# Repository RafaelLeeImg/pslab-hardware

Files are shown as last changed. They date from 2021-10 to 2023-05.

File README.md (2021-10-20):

# PSLab Hardware





This is a special branch `diff-img` where the changes made on all four layers relative to the immediate previous board is presented as a diff image.

## Current Layers

<details>
  <summary>External Layers</summary>

| Top | Bottom |
| --- | --- |
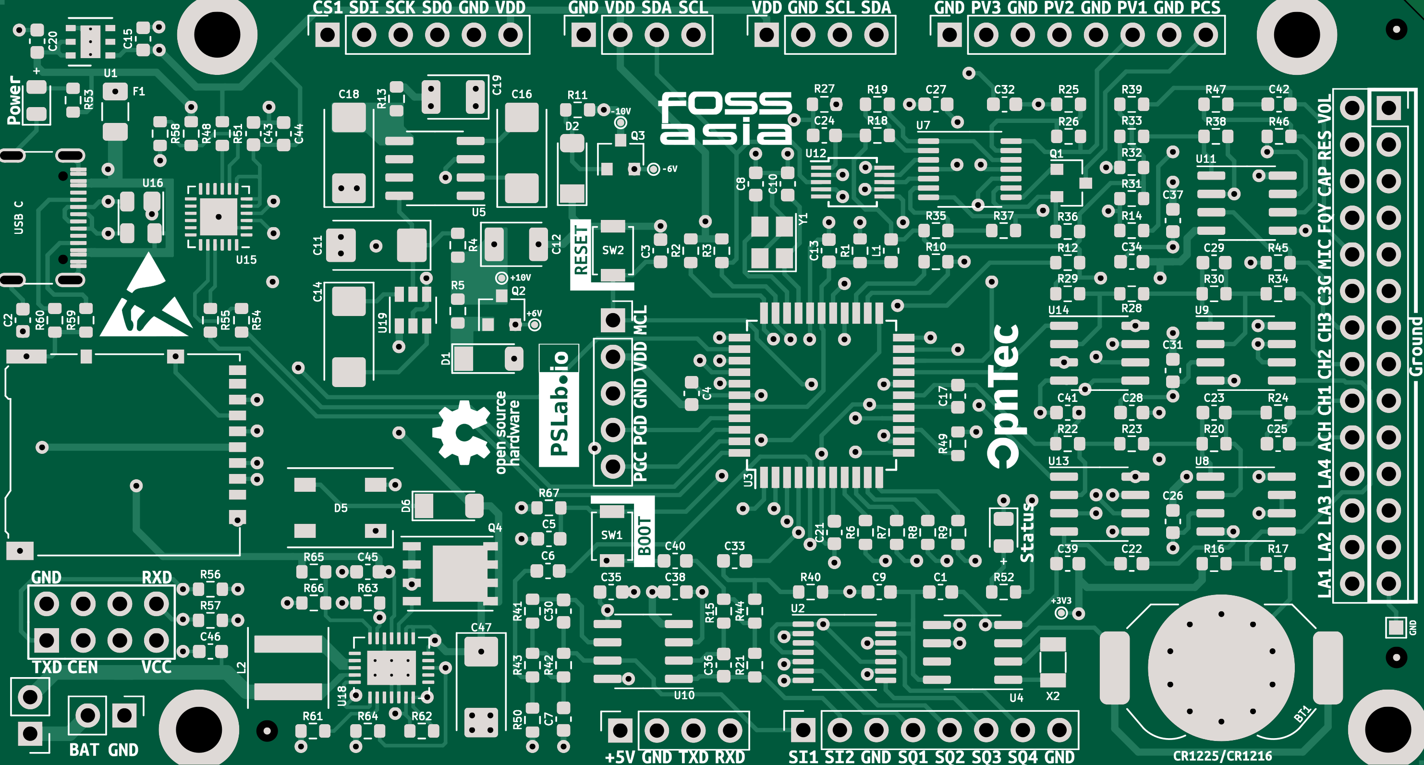
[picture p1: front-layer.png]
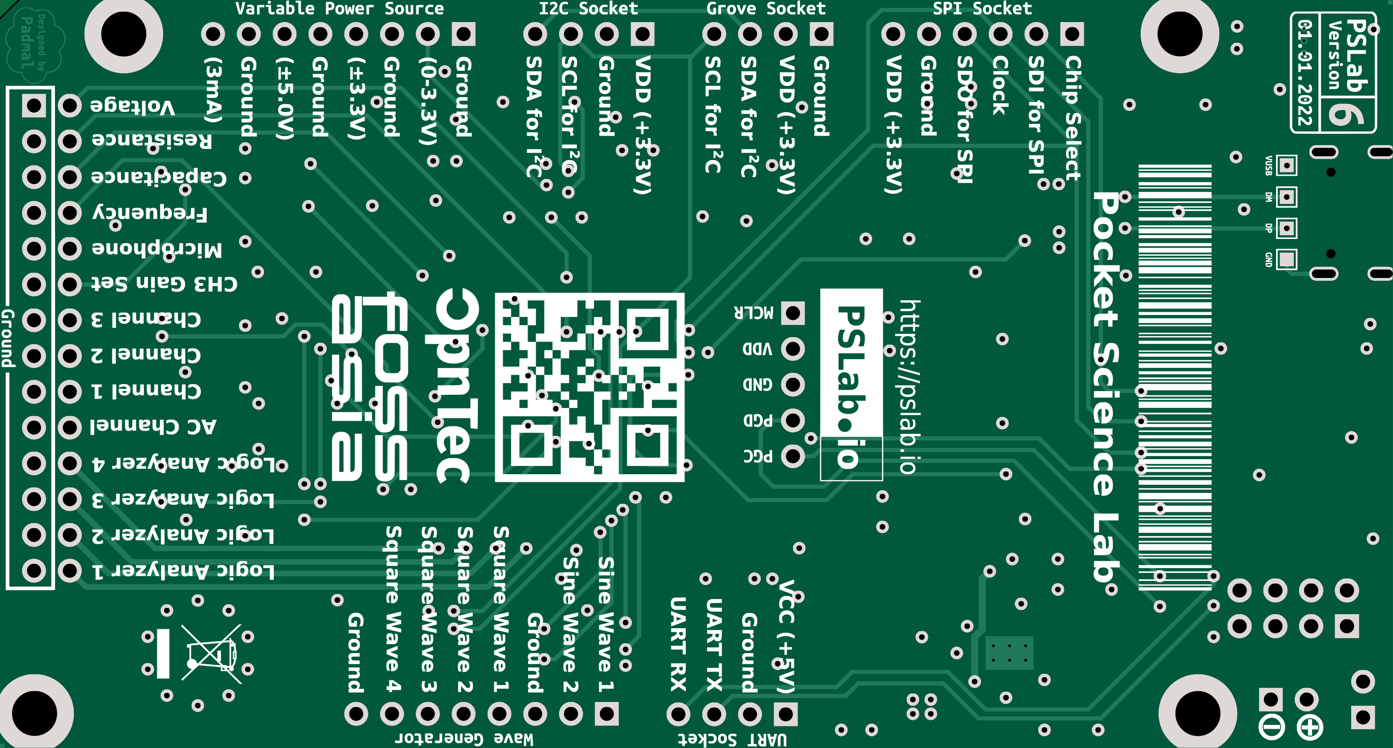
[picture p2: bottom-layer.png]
|  |  |
</details>

<details>
  <summary>Internal Layers</summary>

| Power | Signal |
| ----- | --- |
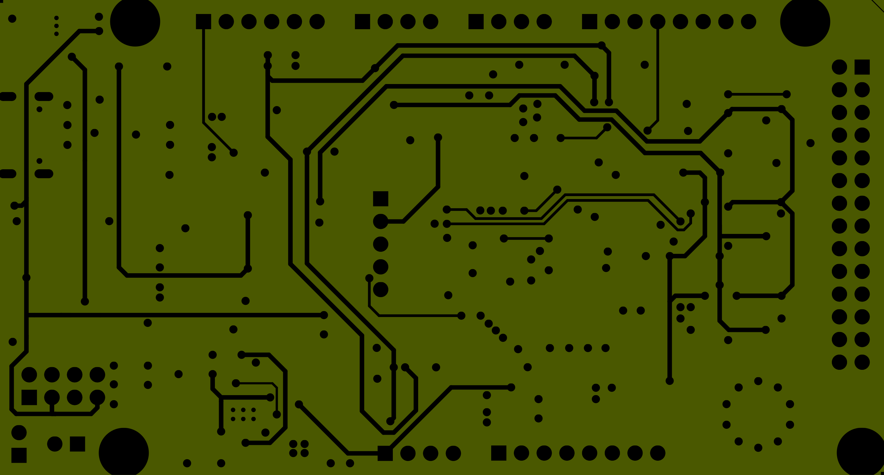
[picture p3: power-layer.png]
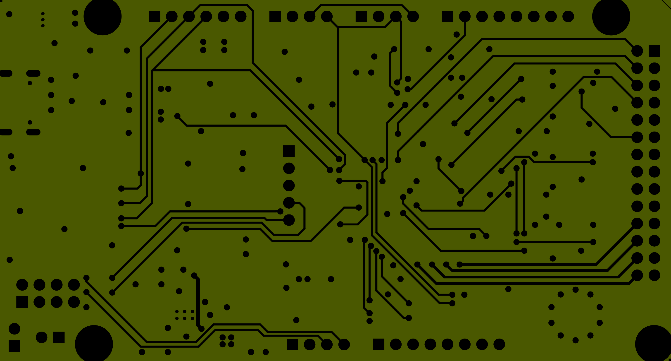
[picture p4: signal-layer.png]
|  |  |
</details>

## Legend

🟥 what the new board has

🟦 what the previous board had

## Schematic Changes
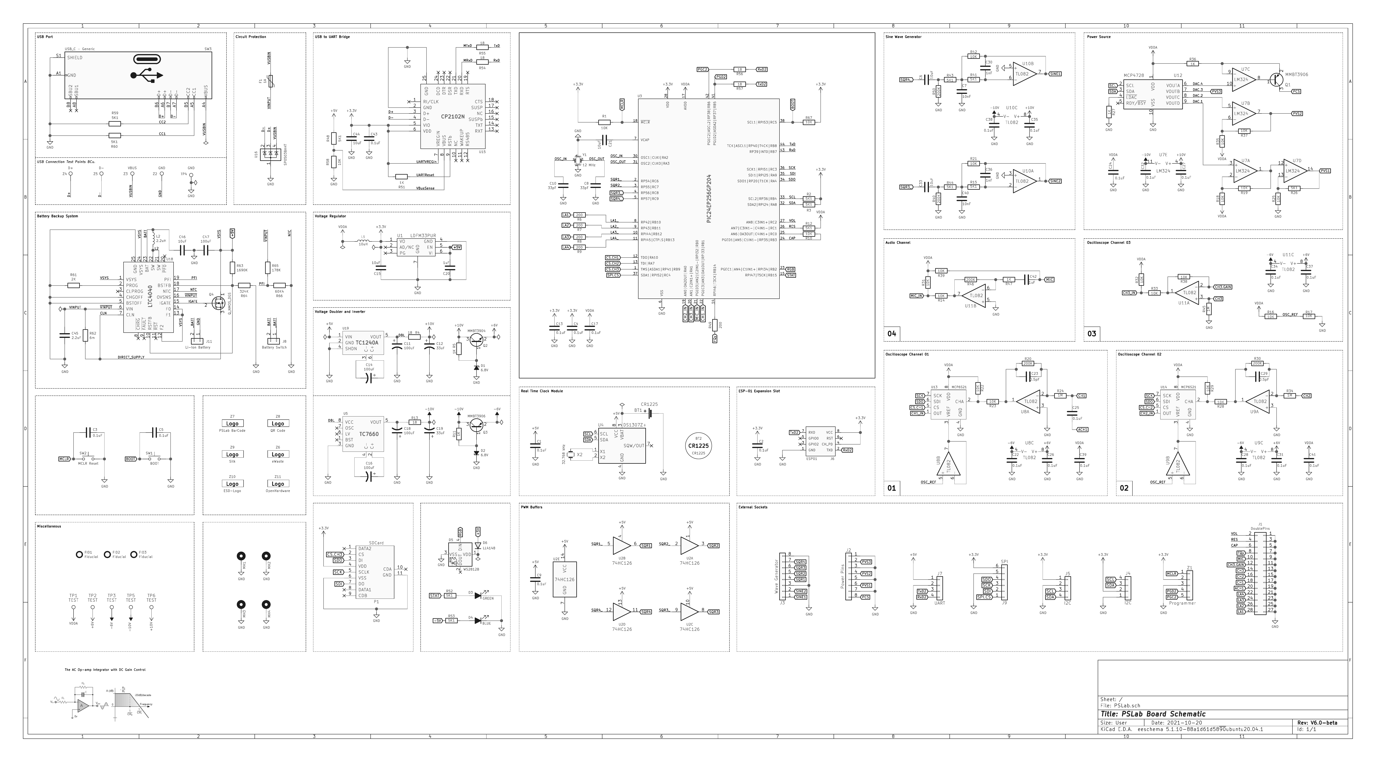
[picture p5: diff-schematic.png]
Schematic


## Board Changes

| Top Layer |
| ---------- |
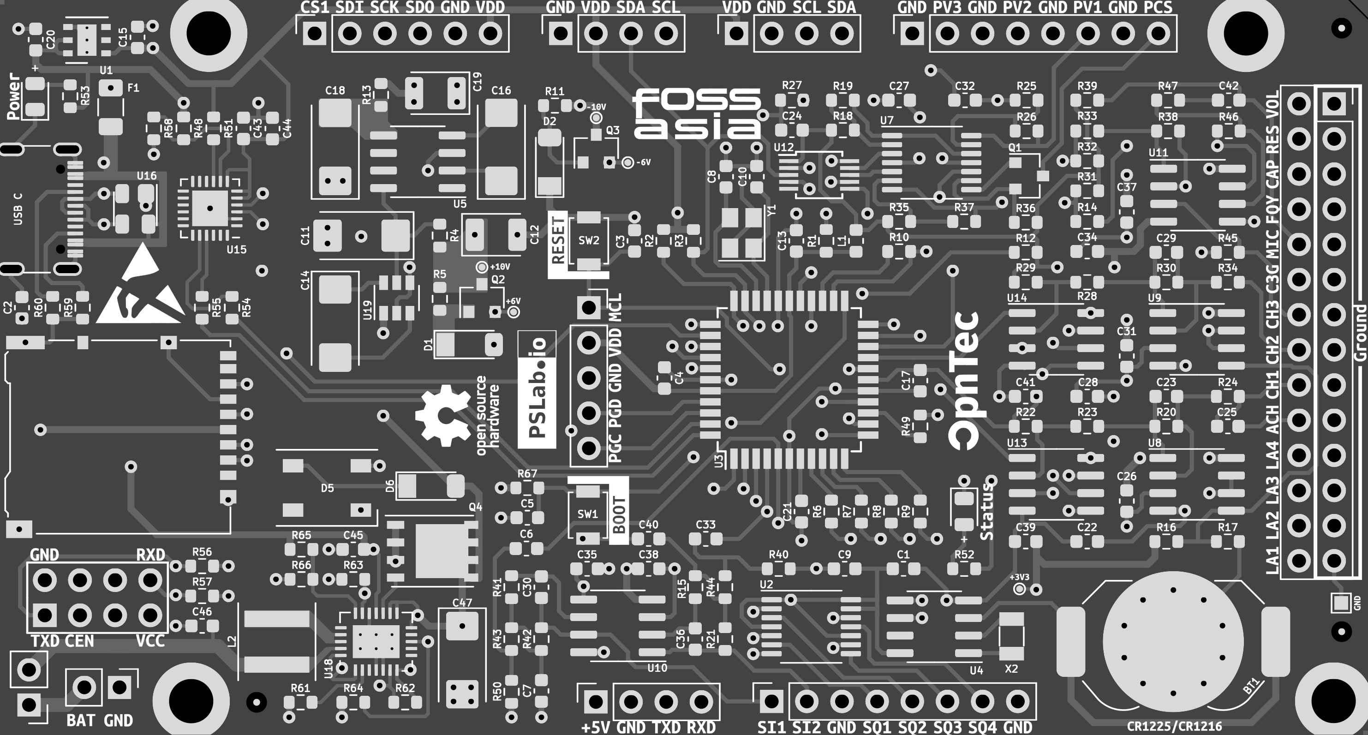
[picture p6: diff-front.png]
Front PCB
|  |

| Bottom Layer |
| --------- |
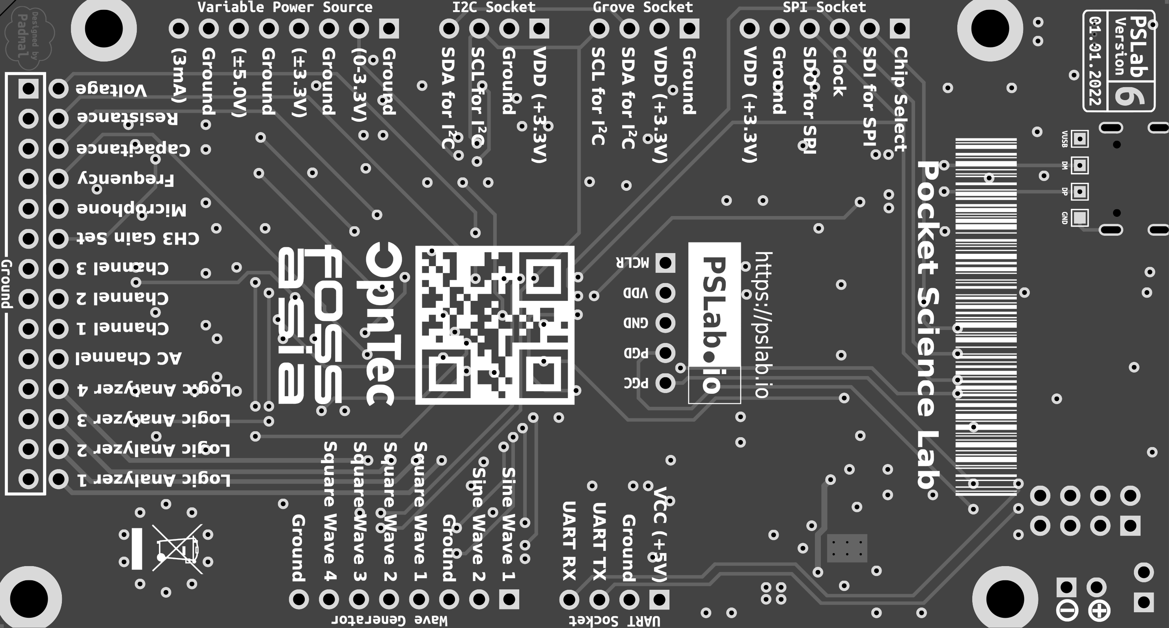
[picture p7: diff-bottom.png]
Rear PCB
|  |

| Power Layer |
| ---------- |
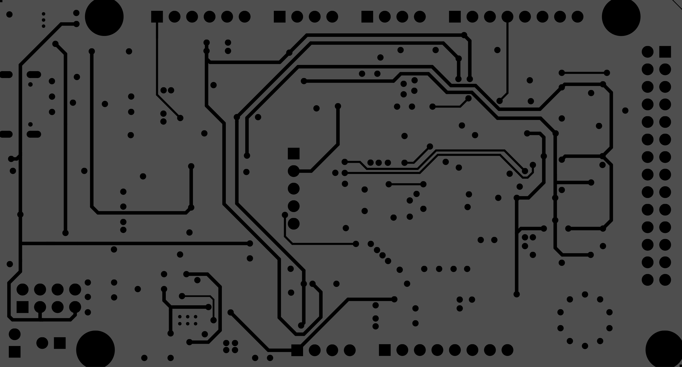
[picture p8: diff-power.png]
Power PCB
|  |

| Signal Layer |
| --------- |
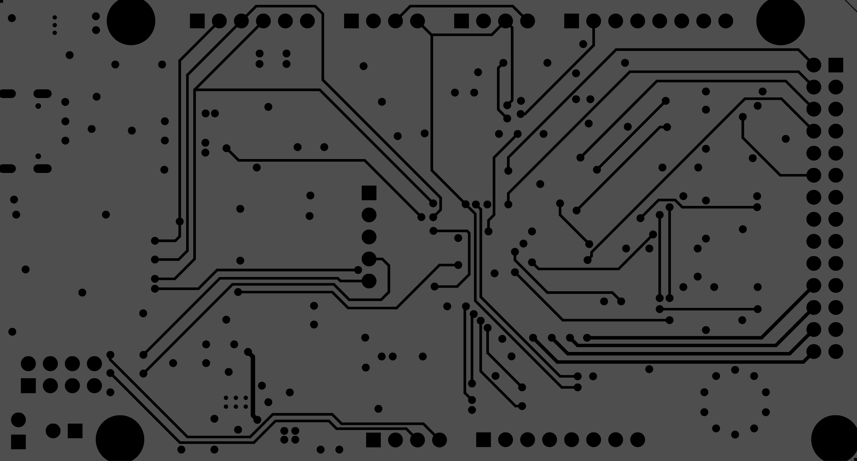
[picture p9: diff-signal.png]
Signal PCB
|  |

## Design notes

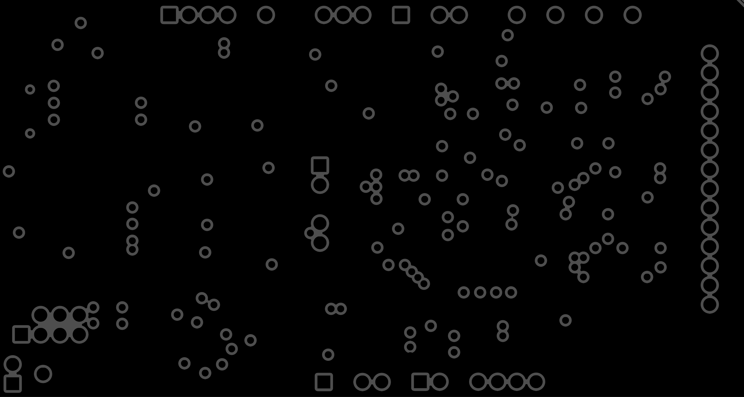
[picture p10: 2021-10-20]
diff-ground.png

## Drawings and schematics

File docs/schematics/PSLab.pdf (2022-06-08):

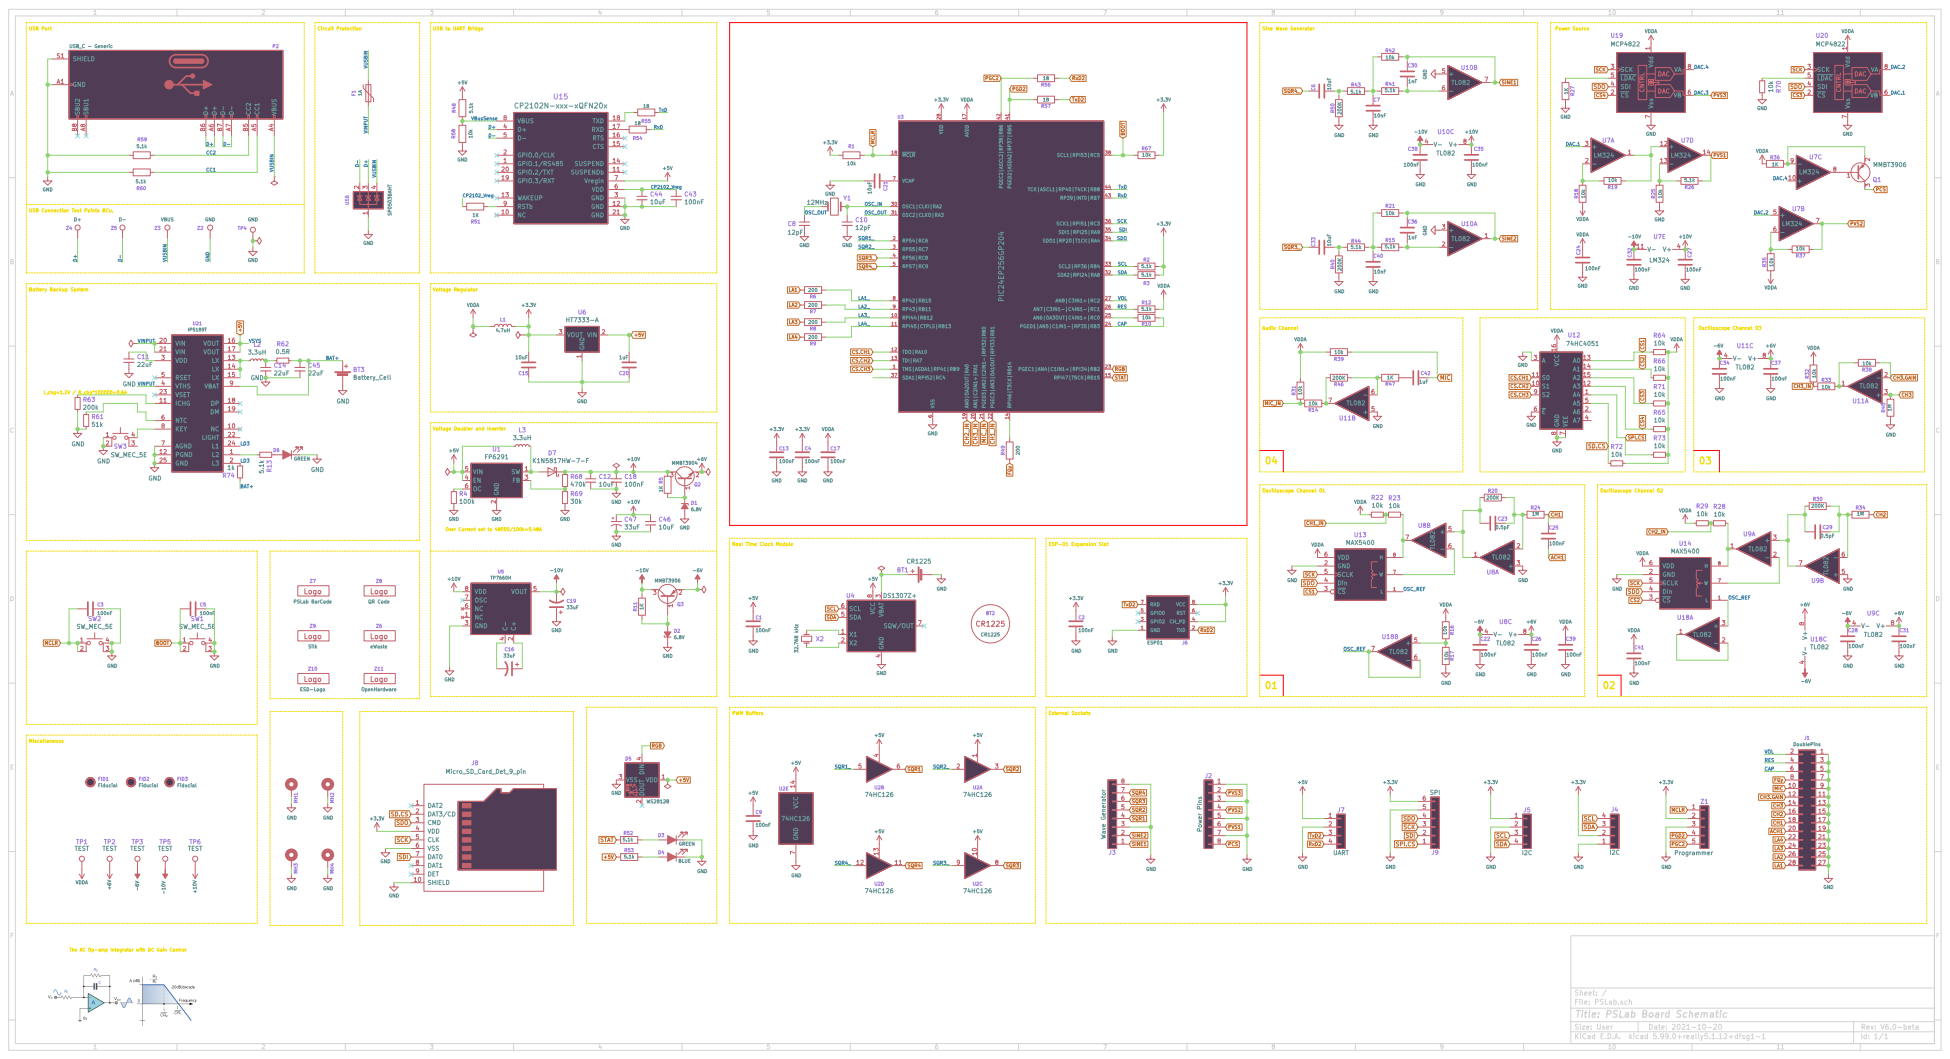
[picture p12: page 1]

Circuit Protection Battery Backup System

2 FB 3 EN 4 VIN 5 OC 6 U1 FP6291

Real Time Clock Module

2 GND 3 C- 4 VOUT 5 NC 6 OSC 7 VDD 8

4 SDA 5 SCL 6 SQW/OUT 7 VCC
SCL

File: PSLab.sch Sheet: /
Id: 1/1 Title: PSLab Board Schematic

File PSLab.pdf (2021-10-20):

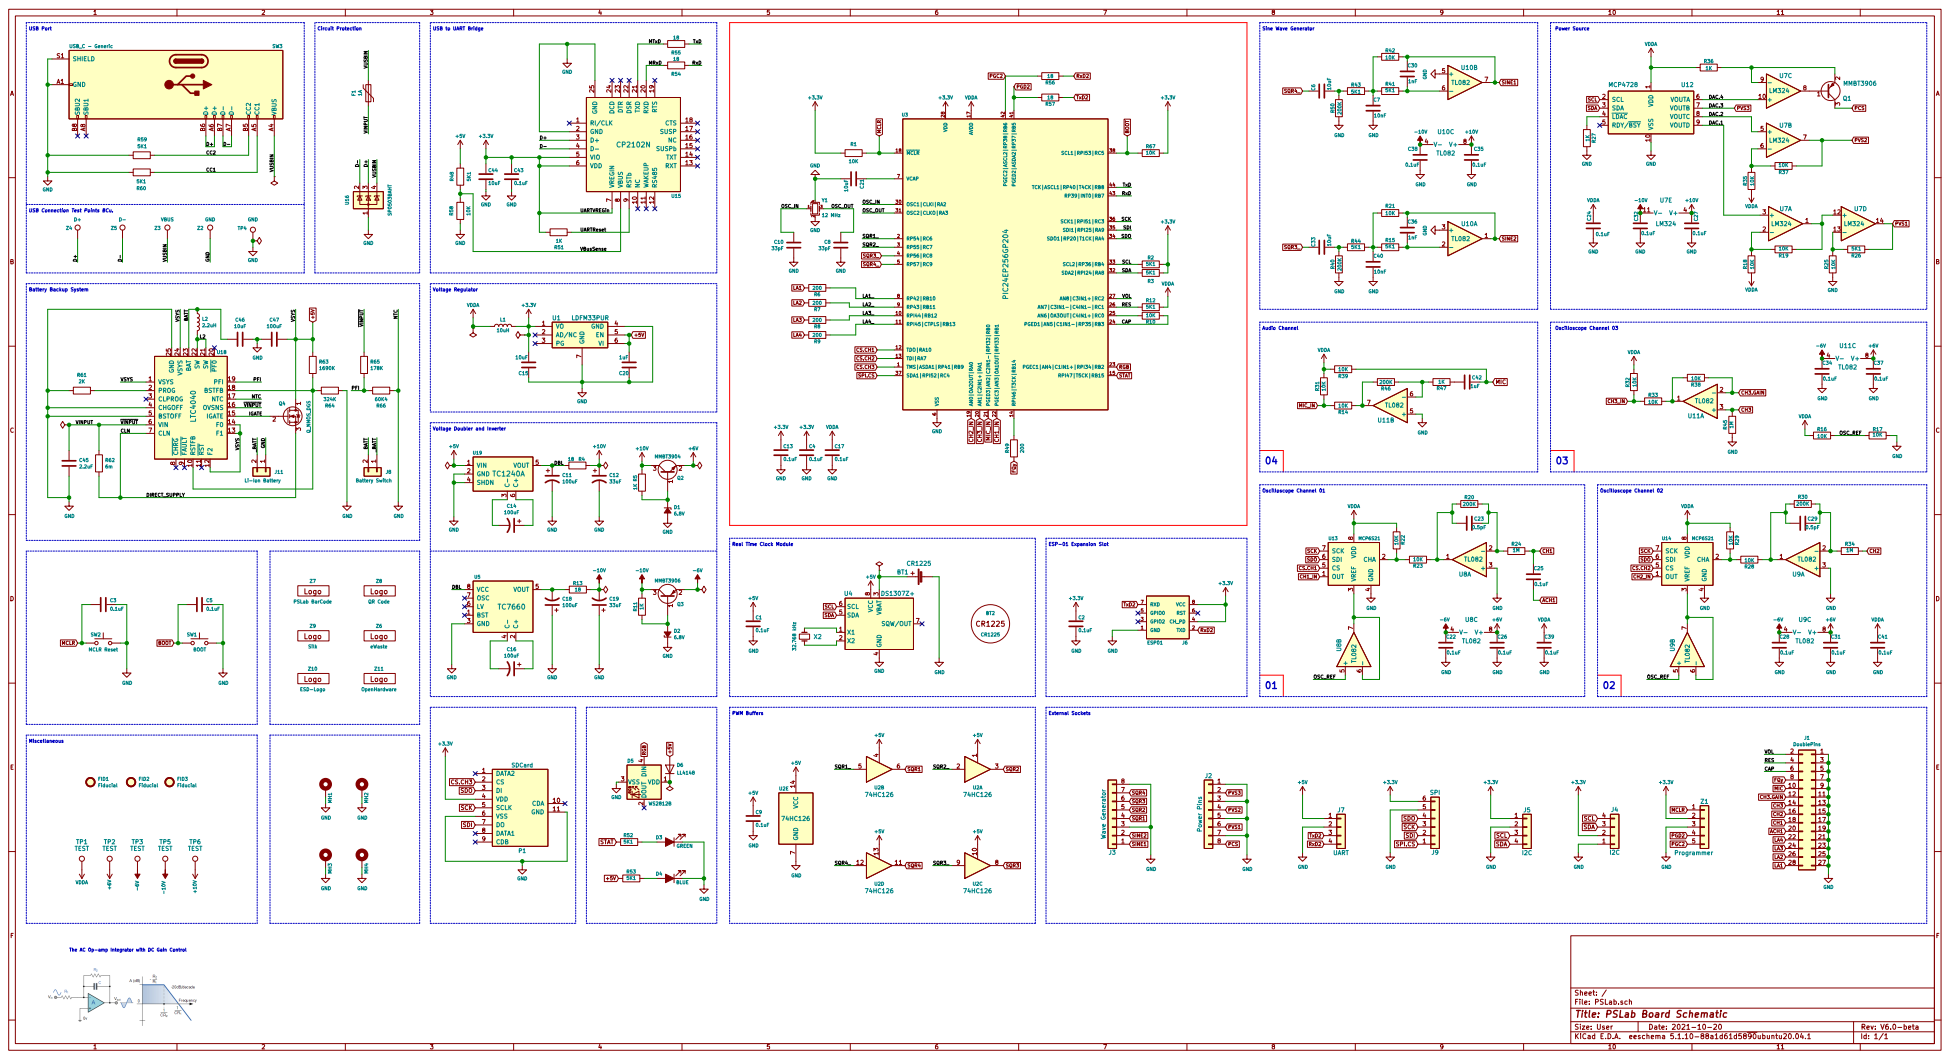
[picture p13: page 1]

Sine Wave Generator Battery Backup System

4 SDA 5 SCL 6 SQW/OUT 7 VCC
SCL

The AC Op-amp Integrator with DC Gain Control

File: PSLab.sch Sheet: /
Id: 1/1 Title: PSLab Board Schematic

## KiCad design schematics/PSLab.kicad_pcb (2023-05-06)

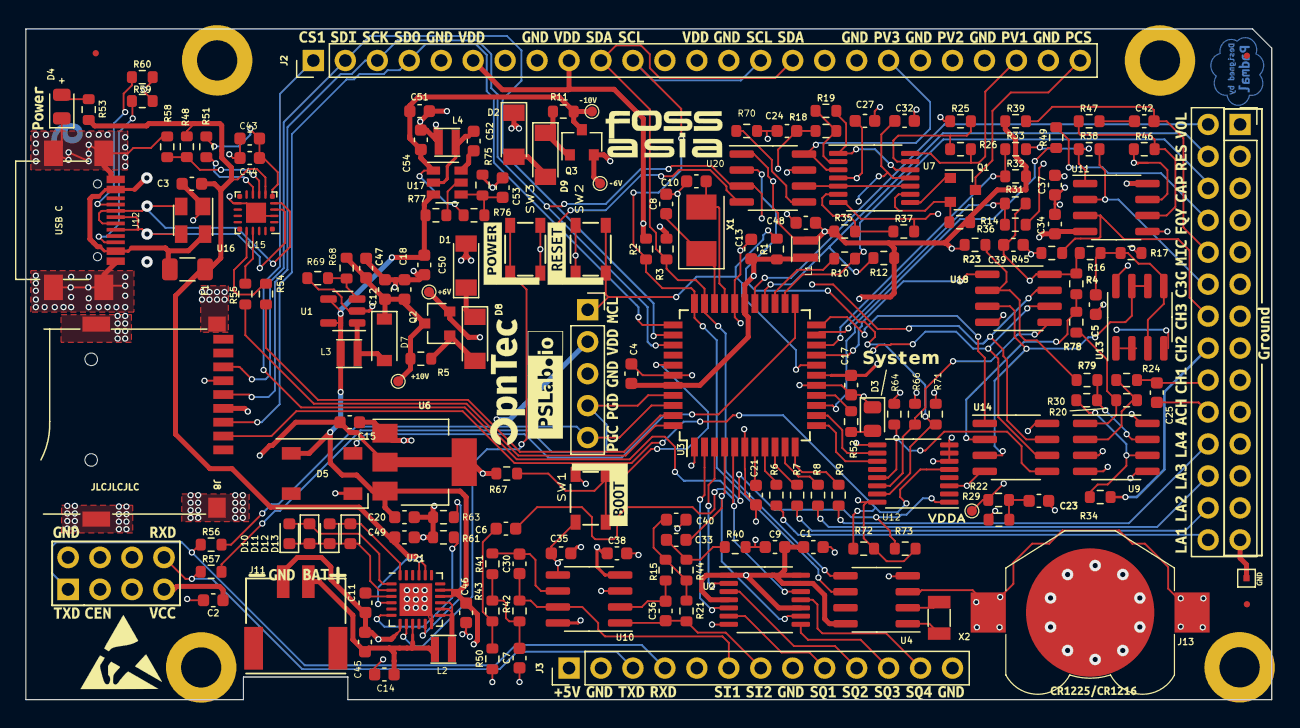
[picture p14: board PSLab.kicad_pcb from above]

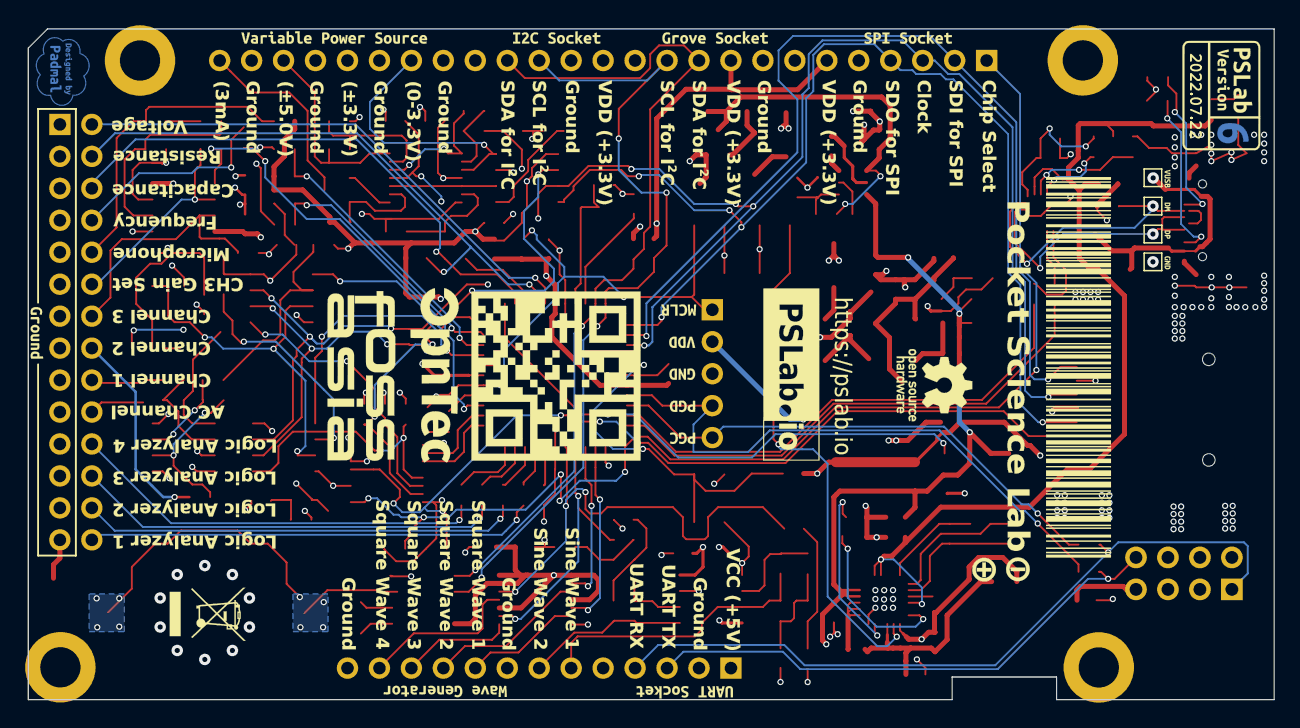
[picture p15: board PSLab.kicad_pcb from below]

Board: 4 copper layers, 99.0 x 53.3 mm, 195 parts (8 on the bottom side), 135 nets.

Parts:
C1, C2, C3, C4, C9, C13, C17, C18, C24, C25, C27, C32, C34, C35, C37, C38, C39, C43: 100nF; C_0603_1608Metric
C5, C7, C23, C40: 10nF; C_0603_1608Metric
C6, C12, C14, C15, C21, C33, C44: 10uF; C_0603_1608Metric
C8, C10, C53: 12pF; C_0603_1608Metric
C11: 2.2uF; C_0603_1608Metric
C20, C42, C52: 1uF; C_0603_1608Metric
C30, C36: 1nF; C_0603_1608Metric
C45, C46, C47, C48, C49, C50, C51, C54: 22uF; C_0603_1608Metric
D1, D2: 6.8V; D_MiniMELF
D3: GREEN; LED_0805_2012Metric
D4: BLUE; LED_0805_2012Metric
D5: WS2812B; LED_WS2812B_PLCC4_5.0x5.0mm_P3.2mm
D7: K1N5817HW-7-F; D_SOD-123
D8, D9: 1N4148W; D_MiniMELF
D10, D11, D12, D13: White; LED_0603_1608Metric
F1: 1A; Fuse_1206_3216Metric
FID1, FID2, FID3: Fiducial; Fiducial_0.5mm_Mask1.5mm
J1: DoublePins; PinSocket_2x14_P2.54mm_Vertical
J2: Conn_01x25; PinHeader_1x25_P2.54mm_Vertical
J3: Conn_01x13; PinHeader_1x13_P2.54mm_Vertical
J6: ESP01; ESP-01
J8: Micro_SD_Card_Det_9_pin; TF-015
J10: Programmer; PinSocket_1x05_P2.54mm_Vertical
J11: Battery_Cell; 2.0mm_connector_edge
J12: USB_C - Generic; USB_C_Receptacle_12pin_SMT
J13: CR1225; BatteryHolder_A359
L1, L3, L4: 3.3uH; L_Taiyo-Yuden_MD-2020
L2: 4.7uH; L_Taiyo-Yuden_MD-2020
MH1, MH2, MH3, MH4: M; MountingHole_3.2mm_M3_DIN965_Pad
Q1, Q3: MMBT3906; SOT-23
Q2: MMBT3904; SOT-23
R1, R4, R10, R14, R16, R17, R18, R19, R21, R23, R25, R29, R31, R32, R33, R35, R37, R38, R39, R42, R58, R64, R66, R67, R70, R71, R72, R73, R76, R78, R79: 10k; R_0603_1608Metric
R2, R3, R12, R15, R26, R41, R43, R44, R48, R52, R53, R59, R60: 5.1k; R_0603_1608Metric
R5, R11, R36, R47, R51: 1k; R_0603_1608Metric
R6, R7, R8, R9, R49: 200; R_0603_1608Metric
R20, R30, R40, R46, R50, R63, R77: 200k; R_0603_1608Metric
R22: 12k; R_0603_1608Metric
R24, R34, R45: 1M; R_0603_1608Metric
R54, R55, R56, R57: 18; R_0603_1608Metric
R61: 51k; R_0603_1608Metric
R68: 180k; R_0603_1608Metric
R69: 30k; R_0603_1608Metric
R75: 100k; R_0603_1608Metric
SW1, SW2, SW3: SW_MEC_5E; button_SPST_3x4x2.5
TP1, TP2, TP3, TP5, TP6: TEST; Test_Point_0.8mm
TP4, TP7: GND; TestPoint_Pad_1.0x1.0mm
TP8: VBUS; TestPoint_Pad_1.0x1.0mm
TP9: D-; TestPoint_Pad_1.0x1.0mm
TP10: D+; TestPoint_Pad_1.0x1.0mm
U1: AP3015A; SOT-23-5
U2: 74HC126; TSSOP-14_4.4x5mm_P0.65mm
U3: PIC24EP256GP204; TQFP-44_10x10mm_P0.8mm
U4: DS1307Z+T&R; SOIC-8_3.9x4.9mm_P1.27mm
U6: AMS1117-3.3; SOT-223-3_TabPin2
U7: LM324; TSSOP-14_4.4x5mm_P0.65mm
U9, U10, U11, U13: TL082; SOIC-8_3.9x4.9mm_P1.27mm
U12: 74HC4051; TSSOP-16_4.4x5mm_P0.65mm
U14, U18: MCP6S21-I/SN; SOIC-8_3.9x4.9mm_P1.27mm
U15: CP2102N-xxx-xQFN20x; QFN-20_EP_3x3_Pitch0.5mm
U16: SP0503BAHT; SOT-143
U17: MT1470; SOT-23-6
U20: MCP4822; SOIC-8_3.9x4.9mm_P1.27mm
U21: IP5189T; QFN-24-1EP_4x4mm_P0.5mm_EP2.6x2.6mm
X1: 12MHz; Crystal_SMD_5032-2Pin_5.0x3.2mm
X2: 32.768 kHz; Crystal_SMD_3215-2Pin_3.2x1.5mm
Z1: CR1225; Battery_CR1225
Z6: eWaste; WEEE-Logo_4.2x6mm_SilkScreen
Z7: PSLab BarCode; Barcode
Z8: QR Code; Website_QR
Z9: Val**; Silk
Z10: ESD-Logo; ESD-Logo_6.6x6mm_SilkScreen
Z11: OpenHardware; OSHW-Logo_5.7x6mm_SilkScreen

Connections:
+3V3: C2.1, C4.1, C13.1, C15.2, J2.6, J2.9, J2.13, J6.4 (CH_PD), J6.8 (VCC), J8.4 (VDD), J10.2, L1.2, R1.1, R2.2, R3.2, R64.2, R66.2, R67.2, R71.2, R72.2, R73.2, U3.28 (VDD), U3.40 (VDD), U6.2 (VO), U12.16 (VCC)
+5V: C1.1, C9.1, C20.2, C46.1, C50.1, D5.1 (VDD), J3.1, L3.1, R77.1, U1.4 (EN), U1.5 (VIN), U2.1, U2.4, U2.10, U2.13, U2.14 (VCC), U4.8 (VCC), U6.3 (VI), U17.3 (IN), U21.16 (VOUT), U21.17 (VOUT)
+6V: C27.1, C35.1, C37.1, Q2.2 (E), TP2.1, U7.4 (V+), U9.8 (V+), U10.8 (V+), U11.8 (V+), U13.8 (V+)
+9V: C12.1, C18.1, C47.1, D7.1 (K), Q2.3 (C), R5.2, R68.1, TP6.1
-6V: C32.1, C34.1, C38.1, Q3.2 (E), TP3.1, U7.11 (V-), U9.4 (V-), U10.4 (V-), U11.4 (V-), U13.4 (V-)
-9V: C51.2, C54.2, Q3.3 (C), R11.2, R76.2, TP5.1, U17.1 (GND)
/BAT+: C14.1, C45.1, J11.1 (+), L2.2, U21.9 (VBAT)
/CAP: J1.6, R10.2, U3.24 (PGED1|AN5|C1IN1-|RP35|RB3)
/CC1: J12.A5 (CC1), R60.2
/CC2: J12.B5 (CC2), R59.2
/CP2102_Vreg: C43.1, C44.1, R51.2, U15.6 (VDD)
/D+: J12.A6 (D+), J12.B6 (D+), TP10.1, U15.4 (D+), U16.3 (K)
/D-: J12.A7 (D-), J12.B7 (D-), TP9.1, U15.5 (D-), U16.2 (K)
/DAC.2: U7.5 (+), U7.10 (+), U20.6 (VB)
/LA1_: R6.2, U3.8 (RP42|RB10)
/LA2_: R7.2, U3.9 (RP43|RB11)
/LA3_: R8.2, U3.10 (RPI44|RB12)
/LA4_: R9.2, U3.11 (RPI45|CTPLS|RB13)
/LD1: D12.2 (A), D13.1 (K), U21.24 (L1)
/LD2: D10.2 (A), D11.1 (K), U21.1 (L2)
/LD3: D10.1 (K), D11.2 (A), D12.1 (K), D13.2 (A), U21.2 (L3)
/OSC_IN: C10.1, U3.30 (OSC1|CLKI|RA2), X1.2
/OSC_OUT: C8.1, U3.31 (OSC2|CLKO|RA3), X1.1
/OSC_REF1: U13.6 (-), U13.7, U14.3 (VREF), U18.3 (VREF)
/OSC_REF2: C23.1, R22.1, R29.1
/RES: J1.4, R12.1, U3.26 (AN7|C3IN1-|C4IN1-|RC1)
/RxD: R54.2, U3.43 (RP39|INT0|RB7)
/SQR1_: U2.5, U3.2 (RP54|RC6)
/SQR2_: U2.2, U3.3 (RP55|RC7)
/TxD: R55.2, U3.44 (TCK|ASCL1|RP40|T4CK|RB8)
/VBusSense: R48.2, R58.2, U15.8 (VBUS)
/VINPUT: C3.2, C49.1, F1.2, R48.1, R53.1, U15.7 (VregIn), U21.4 (VTHS), U21.20 (VIN), U21.21 (VIN)
/VOL: J1.2, U3.27 (AN8|C3IN1+|RC2)
/VUSBIN: F1.1, J12.A4 (VBUS), J12.A9 (VBUS), J12.B4 (VBUS), J12.B9 (VBUS), TP8.1, U16.4 (K)
ACH1: C25.2, J1.20
BOOT: R67.1, SW1.1, SW1.2, U3.38 (SCL1|RPI53|RC5)
CH1: C25.1, J1.18, R24.2
CH1_IN: U3.22 (PGEC3|AN3|OA1OUT|RPI33|RB1), U14.1 (OUT)
CH2: J1.16, R34.1
CH2_IN: U3.19 (AN0|OA2OUT|RA0), U18.1 (OUT)
CH3: J1.14, R45.2, U11.3 (+)
CH3.GAIN: J1.12, R38.1, U11.2 (-)
CH3_IN: R32.1, R33.1, U3.20 (AN1|C2IN1+|RA1)
CS1: R64.1, U12.13 (A0), U14.5 (CS)
CS2: R66.1, U12.14 (A1), U18.5 (CS)
CS3: R71.1, U12.15 (A2), U20.2 (~CS)
CS.CH1: U3.12 (TDO|RA10), U12.11 (S0)
CS.CH2: U3.13 (TDI|RA7), U12.10 (S1)
CS.CH3: U3.1 (TMS|ASDA1|RP41|RB9), U12.9 (S2)
FQy: J1.8, R49.2
GND: C1.2, C2.2, C3.1, C4.2, C5.2, C7.2, C8.2, C9.2, C10.2, C11.2, C12.2, C13.2, C14.2, C15.1, C17.2, C18.2, C20.1, C21.2, C23.2, C24.1, C27.2, C32.2, C34.2, C35.2, C37.2, C38.2, C39.2, C40.2, C43.2, C44.2, C45.2, C46.2, C47.2, C48.2, C49.2, C50.2, C51.1, C53.1, C54.1, D1.2 (A), D2.1 (K), D3.1 (K), D4.1 (K), D5.3 (VSS), J1.1, J1.3, J1.5, J1.7, J1.9, J1.11, J1.13, J1.15, J1.17, J1.19, J1.21, J1.23, J1.25, J1.27, J2.5, J2.8, J2.14, J2.18, J2.20, J2.22, J2.24, J3.2, J3.8, J3.13, J6.1 (GND), J8.6 (VSS), J8.10 (SHIELD), J10.3, J11.2 (-), J12.A1 (GND), J12.A12 (GND), J12.B1 (GND), J12.B12 (GND), J12.S1 (SHIELD), J13.2 (-), L4.2, MH1.1, MH2.1, MH3.1, MH4.1, R17.2, R25.1, R29.2, R40.1, R45.1, R50.1, R58.1, R59.1, R60.1, R61.2, R63.2, R69.2, R70.1, R75.1, SW1.3 (K), SW1.4 (A), SW2.3 (K), SW2.4 (A), SW3.1, SW3.2, TP4.1, TP7.1, U1.2 (GND), U2.7 (GND), U3.6 (VSS), U3.16 (GND), U3.29 (VSS), U3.39 (VSS), U4.4 (GND), U6.1 (GND), U9.3 (+), U9.5 (+), U10.3 (+), U10.5 (+), U11.5 (+), U12.3 (A), U12.6 (~E), U12.7 (VEE), U12.8 (GND), U14.4 (GND), U15.3 (GND), U15.12 (GND), U15.21 (GND), U16.1 (A), U18.4 (GND), U20.7 (Vss), U21.7 (AGND), U21.12 (PGND), U21.25 (GND)
LA1: J1.28, R6.1
LA2: J1.26, R7.1
LA3: J1.24, R8.1
LA4: J1.22, R9.1
MCLR: J10.1, R1.2, SW2.1, SW2.2, U3.18 (~MCLR)
MIC: C42.2, J1.10, R39.1
MIC_IN: R14.1, R31.2, U3.21 (PGED3|AN2|C2IN1-|RPI32|RB0)
unnamed: C5.1, R16.1, R17.1, U13.3 (+), U13.5 (+)
unnamed: C6.2, R43.1, R50.2
unnamed: C7.1, R41.1, R42.1, R43.2
unnamed: C11.1, U21.3 (VDD)
unnamed: C21.1, U3.7 (VCAP)
unnamed: C30.2, R41.2, U10.6 (-)
unnamed: C33.2, R40.2, R44.2
unnamed: C36.2, R15.2, U10.2 (-)
unnamed: C40.1, R15.1, R21.1, R44.1
unnamed: C42.1, R47.1
unnamed: C52.1, L4.1, U17.2 (SW)
unnamed: C52.2, U17.6 (BST)
unnamed: C53.2, R75.2, R76.1, U17.4 (FB)
unnamed: D1.1 (K), D8.1 (K)
unnamed: D2.2 (A), D9.2 (A)
unnamed: D3.2 (A), R52.2
unnamed: D4.2 (A), R53.2
unnamed: D7.2 (A), L3.2, U1.1 (SW)
unnamed: D8.2 (A), Q2.1 (B), R5.1
unnamed: D9.1 (K), Q3.1 (B), R11.1
unnamed: J13.1 (+), U4.3 (VBAT)
unnamed: L2.1, U21.13 (LX), U21.14 (LX), U21.15 (LX)
unnamed: Q1.1 (B), U7.8
unnamed: Q1.2 (E), R36.1, U7.9 (-)
unnamed: R4.2, R78.2, U14.2 (CHA)
unnamed: R10.1, U3.25 (AN6|OA3OUT|C4IN1+|RC0)
unnamed: R14.2, R46.2, U11.7
unnamed: R18.2, R19.2, U7.2 (-)
unnamed: R19.1, U7.1, U7.12 (+)
unnamed: R20.1, R24.1, U9.2 (-)
unnamed: R20.2, R78.1, U9.1
unnamed: R23.2, R79.2, U18.2 (CHA)
unnamed: R25.2, R26.2, U7.13 (-)
unnamed: R30.1, R79.1, U9.7
unnamed: R30.2, R34.2, U9.6 (-)
unnamed: R33.2, R38.2, U11.1
unnamed: R35.2, R37.1, U7.6 (-)
unnamed: R46.1, R47.2, U11.6 (-)
unnamed: R49.1, U3.14 (RPI46|T3CK|RB14)
unnamed: R51.1, U15.9 (RSTb)
unnamed: R54.1, U15.17 (RXD)
unnamed: R55.1, U15.18 (TXD)
unnamed: R61.1, U21.6 (NTC)
unnamed: R63.1, U21.11 (ICHG)
unnamed: R68.2, R69.1, U1.3 (FB)
unnamed: R70.2, U20.5 (~LDAC)
unnamed: R77.2, U17.5 (EN)
unnamed: SW3.3 (K), SW3.4 (A), U21.8 (KEY)
unnamed: U4.1 (X1), X2.1
unnamed: U4.2 (X2), X2.2
unnamed: U13.1, U13.2 (-)
PCS: J2.25, Q1.3 (C)
PGC2: J10.5, R56.1, U3.42 (PGEC2|ASCL2|RP38|RB6)
PGD2: J10.4, R57.1, U3.41 (PGED2|ASDA2|RP37|RB5)
PVS1: J2.23, R26.1, U7.14
PVS2: J2.21, R37.2, U7.7
PVS3: J2.19, U7.3 (+), U20.8 (VA)
RGB: D5.4 (DIN), U3.23 (PGEC1|AN4|C1IN1+|RPI34|RB2)
RxD2: J3.4, J6.2 (TXD), R56.2
SCK: J2.3, J8.5 (CLK), U3.36 (SCK1|RPI51|RC3), U14.7 (SCK), U18.7 (SCK), U20.3 (SCK)
SCL: J2.11, J2.15, R2.1, U3.33 (SCL2|RP36|RB4), U4.6 (SCL)
SD.CS: J8.2 (DAT3/CD), R72.1, U12.5 (A5)
SDA: J2.10, J2.16, R3.1, U3.32 (SDA2|RPI24|RA8), U4.5 (SDA)
SDI: J2.2, J8.7 (DAT0), U3.35 (SDI1|RPI25|RA9)
SDO: J2.4, J8.3 (CMD), U3.34 (SDO1|RP20|T1CK|RA4), U14.6 (SDI), U18.6 (SDI), U20.4 (SDI)
SINE1: C30.1, J3.6, R42.2, U10.7
SINE2: C36.1, J3.7, R21.2, U10.1
SPI.CS: J2.1, R73.1, U12.1 (A4)
SQR1: J3.9, U2.6
SQR2: J3.10, U2.3
SQR3: J3.11, U2.8
SQR3_: C33.1, U2.9, U3.4 (RP56|RC8)
SQR4: J3.12, U2.11
SQR4_: C6.1, U2.12, U3.5 (RP57|RC9)
STAT: R52.1, U3.15 (RPI47|T5CK|RB15)
TxD2: J3.3, J6.7 (RXD), R57.2
VDDA: C17.1, C24.2, C39.1, C48.1, L1.1, R4.1, R12.2, R16.2, R18.1, R22.2, R23.1, R31.1, R32.2, R35.1, R36.2, R39.2, TP1.1, U3.17 (AVDD), U14.8 (VDD), U18.8 (VDD), U20.1 (Vdd)

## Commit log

2021-10-20 chore: updating board diff images
2021-12-13 chore: modify oscilloscope reference voltage divider resister from 5% to 1%
    [PSLab.sch]
2021-12-13 refactor: modify LDFM33 to HT7333-A
    [PSLab.sch]
2021-12-13 refactor: modify TC1240A to FP6291
    [PSLab.sch]
2021-12-13 refactor: modify TC7660 to TP7660H
    [PSLab.sch]
2021-12-14 refactor: replace LTC4040 with IP5189T
    [PSLab.sch]
2021-12-15 chore: add footprint QFN20-3mmx3mm
2021-12-16 chore: replace switch to SPST_3x4x2.5
    [PSLab.sch]
2021-12-16 refactor: fix all warnings, replace SW1 and SW2, before gerber generation
    [PSLab.kicad_pcb]
2021-12-16 chore: generated gerber
    [PSLab-B_Mask.gbr, PSLab-B_Paste.gbr, PSLab-B_SilkS.gbr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]
2021-12-22 Add battery socket, add SW3
    [PSLab.sch]
2021-12-22 Add battery socket and SW3 in PCB
    [PSLab.kicad_pcb]
2021-12-22 refactor: replace PGA MAX6S@! with TL082 and MAX5400
    [PSLab.sch]
2021-12-22 refactor: replace PGA MAX6S@! with TL082 and MAX5400, modify PCB
    [PSLab.kicad_pcb]
2021-12-22 refactor: replace MCP4728 with 2 MPC4822
    [PSLab.sch]
2021-12-22 chore: update button footprint
2021-12-22 refactor: update PCB
    [PSLab.kicad_pcb]
2021-12-22 Before Send to manufacturer
    [PSLab.kicad_pcb]
2021-12-23 chore: add pull-up resistors to SPI_CS SD_CS pins
    [PSLab.sch]
2021-12-23 chore: update PCB
    [PSLab.kicad_pcb]
2021-12-23 Remove all 100uF capcitors
    [PSLab.sch]
2021-12-23 chore: Delete 100uF capacitors
    [PSLab.kicad_pcb]
2021-12-24 refactor: replace IP5189T to IP5219T
    [PSLab.kicad_pcb, PSLab.sch]
2021-12-24 chore: generate gerber and drill files
    [PSLab-B_Mask.gbr, PSLab-B_Paste.gbr, PSLab-B_SilkS.gbr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]
2021-12-31 chore: modify 0.1uF to 100nF
    [PSLab.sch]
2022-02-16 chore: add footprints
2022-02-16 chore: add tf card schematic symbol with detect
2022-02-16 chore: modify tf card slot
    [PSLab.sch]
2022-02-16 chore: update tf card footprint
    [PSLab.kicad_pcb]
2022-02-16 chore: update gerber files
    [PSLab-B_Mask.gbr, PSLab-B_Paste.gbr, PSLab-B_SilkS.gbr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]
2022-02-16 refactor: replace IP5219 to IP51289T
    [PSLab.sch]
2022-02-16 refactor: replace IP5219 to IP51289T in PCB
    [PSLab.kicad_pcb]
2022-02-16 chore: update gerber
    [PSLab-B_Mask.gbr, PSLab-B_Paste.gbr, PSLab-B_SilkS.gbr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]
2022-03-17 20220302, send to manufacturer
    [PSLab.kicad_pcb, PSLab.sch]
2022-03-17 refactor: generate negative voltage using a buck converter
    [PSLab.kicad_pcb, PSLab.kicad_sch, PSLab.sch]
2022-04-16 Update to kicad6
    [PSLab-B_Mask.gbr, PSLab-B_Paste.gbr, PSLab-B_SilkS.gbr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]
2022-07-21 chore: remove 7660
    [PSLab.kicad_sch]
2022-07-21 For 2022 June
    [PSLab.kicad_pcb]
2022-09-02 refactor: send to manufacturer
    [PSLab-B_Mask.gbr, PSLab-B_Paste.gbr, PSLab-Edge_Cuts.gbr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]
2022-09-03 refactor: update to kicad v6 and generate negative voltage using a buck converter
    [PSLab.kicad_sch, PSLab.sch]
2022-09-03 chore: modify descriptions and silk screens
    [PSLab.kicad_sch]
2023-05-06 chore: modify text status to system of LED
2023-05-06 chore: update silk screen
    [PSLab.kicad_pcb]
2023-05-06 chore: move edge connector inner
    [PSLab.kicad_pcb]
2023-05-06 chore: modify battery silk screen
